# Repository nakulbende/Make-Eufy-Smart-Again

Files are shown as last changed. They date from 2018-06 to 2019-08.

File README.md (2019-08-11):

# Make Eufy smart again!

Make a internet enabled IR controller for EUFY vacuum cleaners. Recent models of EUFY and Roomba vacuum cleaners include smartphone control, and my robot was feeling left out. So - lets make EUFY smart again!

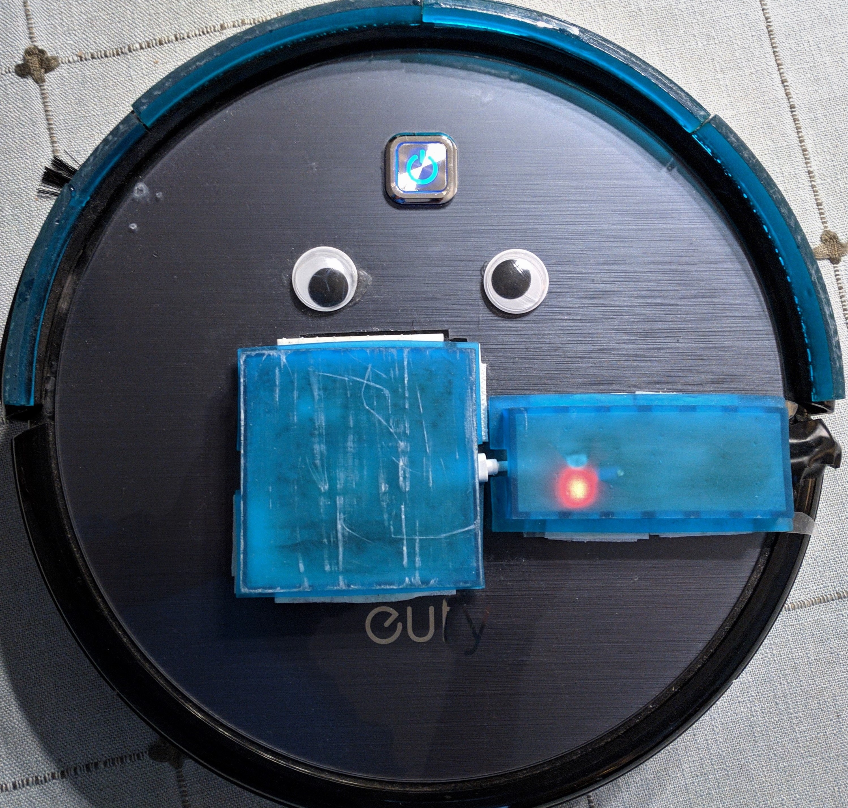
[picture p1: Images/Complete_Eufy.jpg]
Smart EUFY


## What you need: 

- EUFY vacuum cleaner: [non-internet enabled models v11, v11s and v11+](https://www.eufylife.com/collections/cleaning)
- ESP8266 based microcontroller: we use a [esp8266 12E mounted on a nodeMCU devboard v0.9](https://frightanic.com/iot/comparison-of-esp8266-nodemcu-development-boards/) used here, Adafruit Huzzah or any other internet enabled board can be used too
- ~~Battery pack: Slimmer and bigger mAh is better - current example uses a [12000 mAh battery charger](https://smile.amazon.com/gp/product/B077N9KYV8/ref=oh_aui_detailpage_o03_s00?ie=UTF8&psc=1)~~
- **Updated for driving power from Eufy's battery** High efficiency buck convertor for converting 12V from [LM2596S DC to DC Step-down voltage regulator](https://www.ebay.com/itm/1x-10x-LM2596S-DC-DC-3A-Buck-Adjustable-Step-down-Power-Supply-Converter-Module/332711109230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). Uses low energy, low heat output, and now Eufy can be connected all the time!
- IR reciever: [VS1838B](https://smile.amazon.com/Haobase-pairs-Infrared-Emission-Receiver/dp/B01EMXC5XA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) based. Wiring and further details [here](https://chioszrobots.com/2014/02/11/vs1838-tl1838-vs1838b-universal-infrared-receiving-head-remote-control/)
- IR LED: [950 nm](https://smile.amazon.com/Haobase-pairs-Infrared-Emission-Receiver/dp/B01EMXC5XA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) Used like a regular LED
- Misc. supplies: Soldering supplies, wires, proto board, command strip (to mount controller, battery pack)

## Working principle: 

1. This project relies on copying IR codes from the supplied remote, meant for programming EUFY. The idea is to mount a low profile, internet enabled remote on the robot to make it 'smart'. Decoded codes for [Eufy v11](Codes_eufy_v11.txt) are included here. PLEASE PAY ATTENTION TO THE MODEL/ VERSION BEFORE POSTING ISSUES. To avoid issues with revisions/ model differences, please copy the IR codes from supplied remote as discussed shortly. 

2. This project uses the fantastic Blynk project to control board using web requests, and package everything in a nice GUI. Using Blynk servers, we can also enable Google home/ Alexa support using IFTTT. Highly recommend reading through [Blynk docs](http://docs.blynk.cc/) for a basic overview of how it works. 

3. An IR blaster controlled by esp8266, will replay the codes as if they were coming from EUFY's original remote. 

Here is a step-by-step guide for reading IR codes > designing circuit > programming esp8266 > making Blynk GUI > integrating with IFTTT (and optionally with Google Home)

### Reading IR codes from EUFY's remote: (skip if using EUFY v11 - codes are already included in this project)

All the IR send/ recieve commands are interfaced using cyborg5's amazing [IRLib2](https://github.com/cyborg5/IRLib2). Install it from library manager, or follow instructions on repo's github page. Based on library's example [rawRecv](https://github.com/cyborg5/IRLib2/blob/master/IRLib2/examples/rawRecv/rawRecv.ino), we will be reading IR codes with any arduino based board programmed with ([IR_read_RAW_codes](IR_read_RAW_codes/IR_read_RAW_codes.ino). To equip the IR reciever, simply connect pins to 3.3V, GND and digital pin 2. Flash the board with [included code](IR_read_RAW_codes/IR_read_RAW_codes.ino), and open serial monitor with appropriat baud rate. Take your EUFY remote, point it at the reciever, and voila! The code will print the RAW IR code for that particular button. The EUFY's IR reciever is indeed following the exact same procedure to read IR signals from its remote!

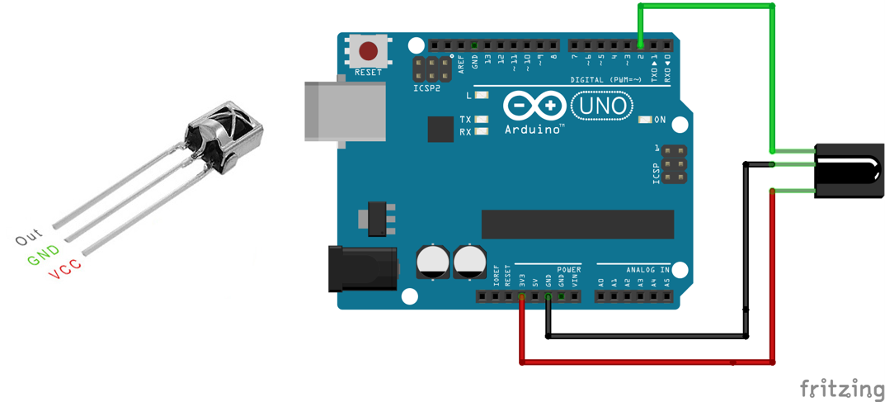
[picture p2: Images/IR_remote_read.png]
Circuit for copying IR codes


For the geeks and nerds out there, most consumer IR signals are carried on a 38kHz carrier frequency, which is also the case here. Some major brands like SONY, NEC and PANASONIC have HEX codes associated with this RAW data, and can be decoded using IRLib2. Since EUFY does not follow any of these standard codes - we will just read and send RAW IR codes - simply an array of numbers representing how long the LEd was ON, followed by how long it was OFF for.

For example, when HOME button is pressed, the raw IR code on serial port is: 

```
Encoding  : UNKNOWN
Code      : E8BEB62D (32 bits)
Timing[83]:
     +2900, -3000     + 500, - 500     + 550, -1400     + 550, -1450
     + 500, - 450     + 550, -1450     + 500, - 450     + 550, - 450
     + 550, - 400     + 550, - 450     + 450, - 550     + 450, - 550
     + 450, - 500     + 550, -1450     + 500, -1450     + 550, -1400
     + 600, -1400     + 550, - 450     + 500, - 450     + 600, - 400
     + 550, - 450     + 500, - 450     + 550, - 450     + 500, - 500
     + 500, - 450     + 450, - 550     + 550, - 450     + 500, - 450
     + 550, - 450     + 550, - 450     + 550, - 450     + 500, - 450
     + 550, - 450     + 550, - 450     + 550, -1400     + 550, -1450
     + 550, -1400     + 450, - 500     + 550, -1450     + 450, -1500
     + 550, -1450     + 550
unsigned int  rawData[83] = {2900,3000, 500,500, 550,1400, 550,1450, 500,450, 550,1450, 500,450, 550,450, 550,400, 550,450, 450,550, 450,550, 450,500, 550,1450, 500,1450, 550,1400, 600,1400, 550,450, 500,450, 600,400, 550,450, 500,450, 550,450, 500,500, 500,450, 450,550, 550,450, 500,450, 550,450, 550,450, 550,450, 500,450, 550,450, 550,450, 550,1400, 550,1450, 550,1400, 450,500, 550,1450, 450,1500, 550,1450, 550};  // UNKNOWN E8BEB62D
```
This denotes a box wave with the led ON for 2900ms, OFF for 3000ms, ON for 500ms, OFF for 450ms and so on. Pressing the same button a couple of times should be used to check consistency of these numbers. Finally, the raw code should be "cleaned" by rounding numbers to obvious extremes: 2900 goes to 3000, 450 and 550 to 500, 1400 to 1500 etc. This is to account for limited resolution. In essence, this same code should have been: 

```
Encoding  : UNKNOWN
Code      : E8BEB62D (32 bits)
Timing[83]:
     +3000, -3000     + 500, - 500     + 500, -1500     + 500, -1500
     + 500, - 500     + 500, -1500     + 500, - 500     + 500, - 500
     + 500, - 500     + 500, - 500     + 500, - 500     + 500, - 500
     + 500, - 500     + 500, -1500     + 500, -1500     + 500, -1500
     + 500, -1500     + 500, - 500     + 500, - 500     + 500, - 500
     + 500, - 500     + 500, - 500     + 500, - 500     + 500, - 500
     + 500, - 500     + 500, - 500     + 500, - 500     + 500, - 500
     + 500, - 500     + 500, - 500     + 500, - 500     + 500, - 500
     + 500, - 500     + 500, - 500     + 500, -1500     + 500, -1500
     + 500, -1500     + 500, - 500     + 500, -1500     + 500, -1500
     + 500, -1500     + 500
unsigned int  rawData[83] = {3000,3000, 500,500, 500,1500, 500,1500, 500,500, 500,1500, 500,500, 500,500, 500,500, 500,500, 500,500, 500,500, 500,500, 500,1500, 500,1500, 500,1500, 500,1500, 500,500, 500,500, 500,500, 500,500, 500,500, 500,500, 500,500, 500,500, 500,500, 500,500, 500,500, 500,500, 500,500, 500,500, 500,500, 500,500, 500,500, 500,1500, 500,1500, 500,1500, 500,500, 500,1500, 500,1500, 500,1500, 500};  // UNKNOWN E8BEB62D
```

[Included codes](Codes_eufy_v11.txt) for EUFY 11 are cleaned and ready to go!

### Circuit for transmitting IR codes using esp8266

The ESP is a wonderful device - packing wifi, digital/ analog IO in such a small footprint is no small feat of engineering. Chinese manufacturers do not get credit for their innovation - ESP is definately an hallmark from Espressif Systems! We will be using a nodeMCU developer board - you can certainly use a esp8266-12E directly if you do not have the board. This is how the circuit should be connected, and the final product: 

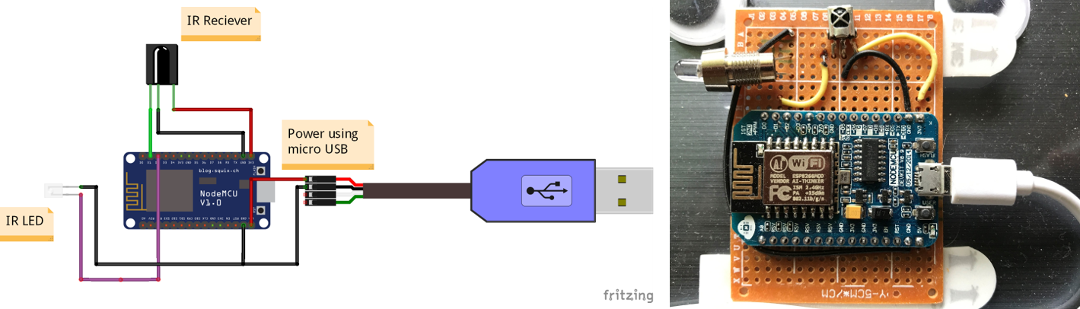
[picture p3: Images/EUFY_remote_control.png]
Circuit and actual product


Mounting options will be discussed later - but make sure you do not block the IR blaster with box/ mounts.  

### Programming esp8266

Flash esp8266 with the [supplied code](/IR_remote_control_EUFY_github/IR_remote_control_EUFY_github.ino) using following settings: 

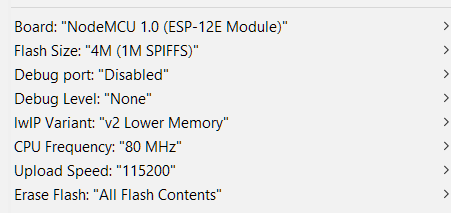
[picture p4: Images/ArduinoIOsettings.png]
Flash settings


The following snippets describe what this code does:

#### [Lines 10 - 15](https://github.com/nakulbende/Make-Eufy-Smart-Again/blob/master/IR_remote_control_EUFY_github/IR_remote_control_EUFY_github.ino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) define connection settings: change according to your Wifi settings and Blynk authentication code

10-12     Define `ssid` and `password` according to wifi settings. 

13        Add new device in Blynk mobile app, and define the authorization token as `auth` 

14-15     We will be pushing over the air updates to your esp8266 to make any changes after first time, so define the `OTAName` and `OTAPassword` to identify and secure it. 

#### [Lines 18 and 19](https://github.com/nakulbende/Make-Eufy-Smart-Again/blob/master/IR_remote_control_EUFY_github/IR_remote_control_EUFY_github.ino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) define the pins on which devices are connected to

Define the GPIO for IR blaster as `IR_LED` and IR reciever as `IR_RECV`. Be careful if nodeMCU dev board is used - enter the actual GPIO pins connected to devices, not the identifiers on board. 

#### [Lines 24-39](https://github.com/nakulbende/Make-Eufy-Smart-Again/blob/master/IR_remote_control_EUFY_github/IR_remote_control_EUFY_github.ino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) define virtual pins for controlling the esp8266 through Blynk

[Virtual pins used in Blynk](http://docs.blynk.cc/#blynk-main-operations-virtual-pins) are defined using `VPIN_*` for all the commands copied from remote. Custom pins such as `VPIN_Connected` and `VPIN_terminal` are used for monitoring connection status and terminal output using Blynk app.

#### [Lines 53-87](https://github.com/nakulbende/Make-Eufy-Smart-Again/blob/master/IR_remote_control_EUFY_github/IR_remote_control_EUFY_github.ino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) define previously copied IR codes 

Store the previously copied IR codes in structured arrays `ir_*`. Change the value of each variable with cleaned values if you are using a different version of EUFY vacuum cleaner. 

#### Rest of the code can be left as is. Upon booting, the device should connect to internet and Blynk servers

### Configuring Blynk GUI:

The virtual pins defined in code (and discussed in previous section) can be assigned to individual buttons in Blynk app. An example of such GUI in making can be seen in following screenshots - feel free to alter or use as is. Although the widgets and settings are self explanatory - [Blynk Widget guide](http://docs.blynk.cc/#widgets) is a great resource!

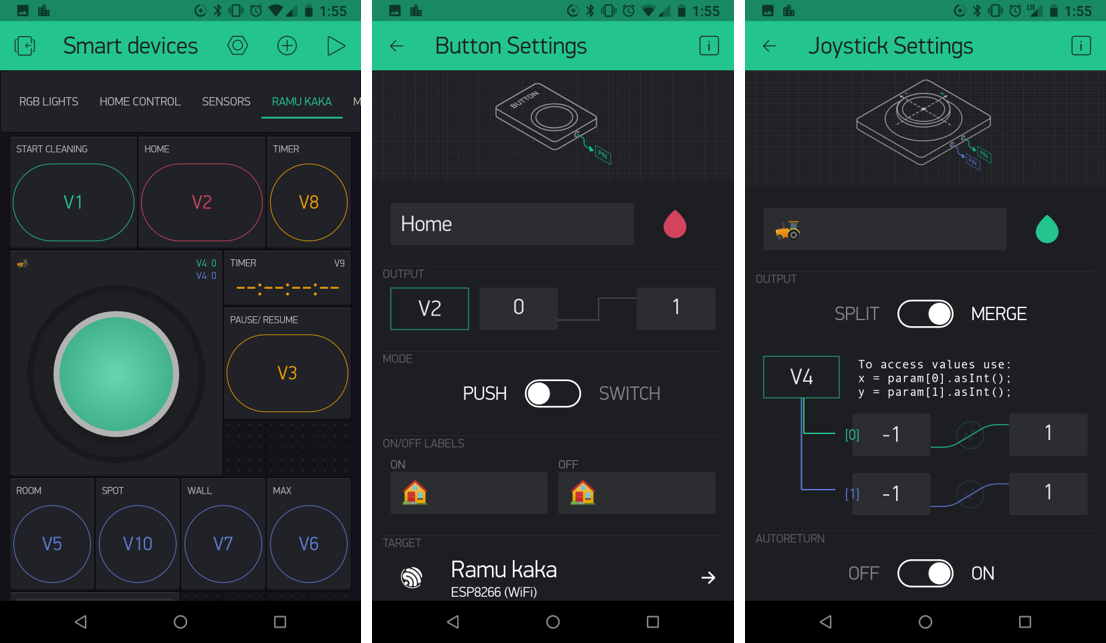
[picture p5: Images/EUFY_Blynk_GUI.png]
Blynk GUI configuration


Finally, the EUFY remote functionality can be replicated on a smartphone. We made EUFY smart again!

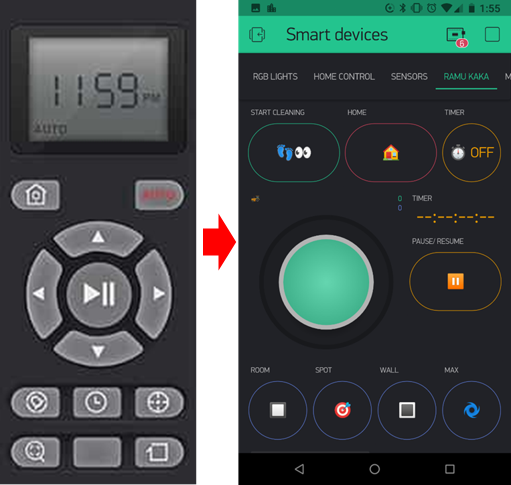
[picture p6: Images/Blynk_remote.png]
Blynk remote


### IFTTT/ Google Home/ Alexa integration

Read/ Write functions can be performed on Blynk virtual/ digital/ analog pins by putting data on the following URL: 

http://`IP: blynk server`/`device authorization code`/pin/`pin identifier`

`IP: blynk server` depends on your location. For US, it is 45.55.96.146. Open terminal and `ping blynk-cloud.com` to resolve the local IP address. Auth code helps in identifying the device, and pins can be defined as D1/ V1 etc. for digital or virtual pin. 

Once URL is ready - use any action to trigger a webhook with following settings. For example, configure gogle assistant trigger to post 1 on V1 for sending Auto clean command to EUFY, whenever it detects "clean the house"

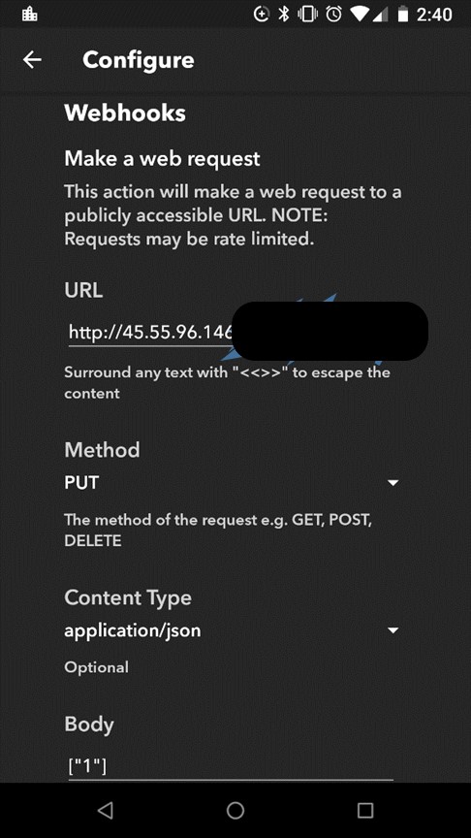
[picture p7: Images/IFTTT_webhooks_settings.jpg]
Webhooks setting


### Mounting options

~~The battery pack and circuit can be mounted on the EUFY using command strips. Due to this, a slim battery pack should be preffered. The product listed only raises the height of EUFY slighly. Getting power directly from the Eufy's battery is to be explored for future revisions. We have already tried getting power from the adapter jack besides the power button - which outputs a DC current, but also puts EUFY in charging mode if it detects a closed circuit.~~  

**Updated 8/11/2019**

Finally got around to posting this. I have converted this setup to be in an always ON state - powered directly by the Eufy's 12V battery. The setup now looks as follows: 

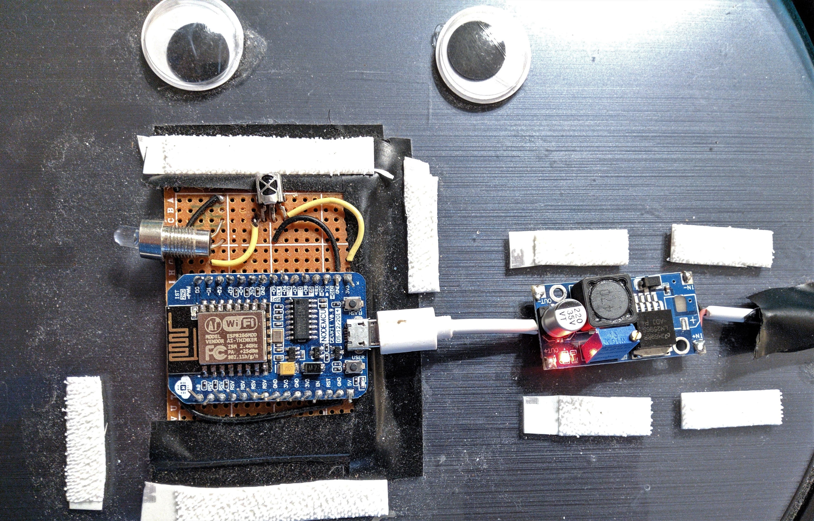
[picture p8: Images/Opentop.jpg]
Circuit, voltage regulator


I used a high efficiency voltage regulator (LM2596S) for converting 12V to 3V which esp8266 needs, and mounted everything using command strips. You do have to work on roputing the wire - I found that using a thin wire, routing it through the sides of bumper like follows works pretty well: 

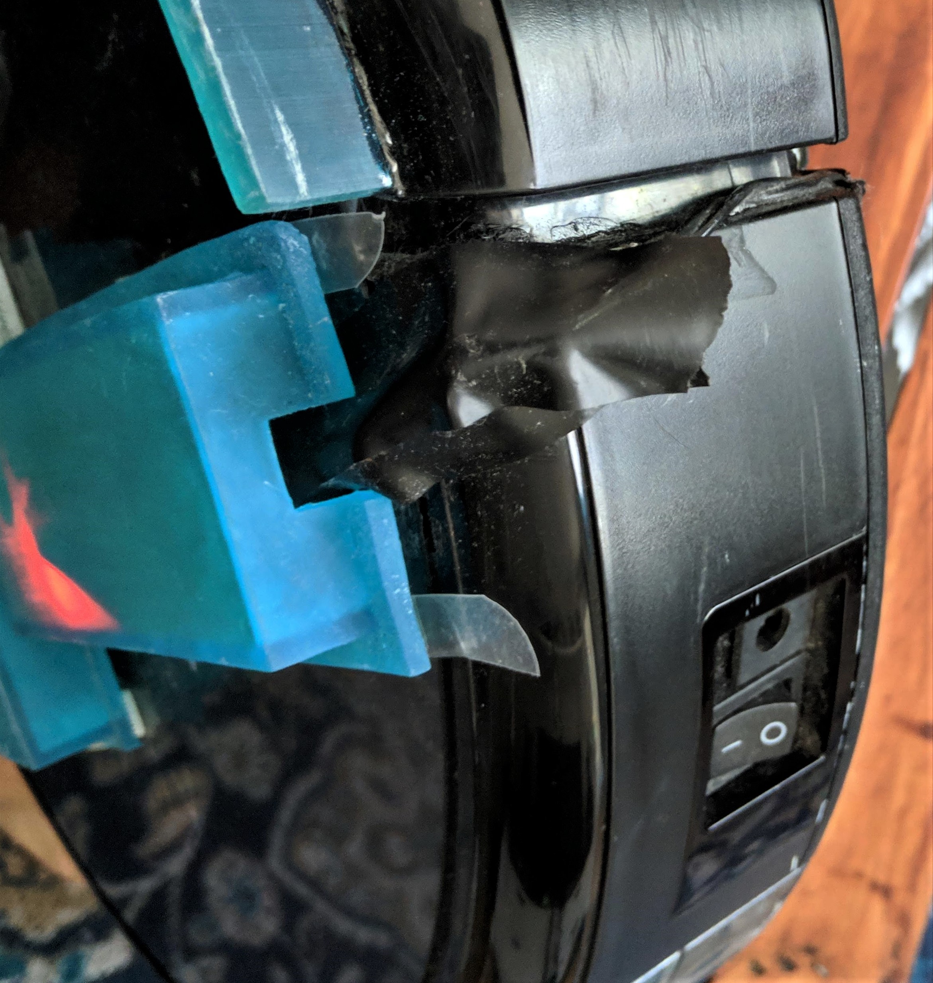
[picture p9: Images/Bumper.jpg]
Routing wire from side, to the belly


Once you have access to Eufy's belly, you can just route the wire to battery compartment. I made a little hole on cover using my soldering iron. There, just slice wires, and take power directly from the battery. 

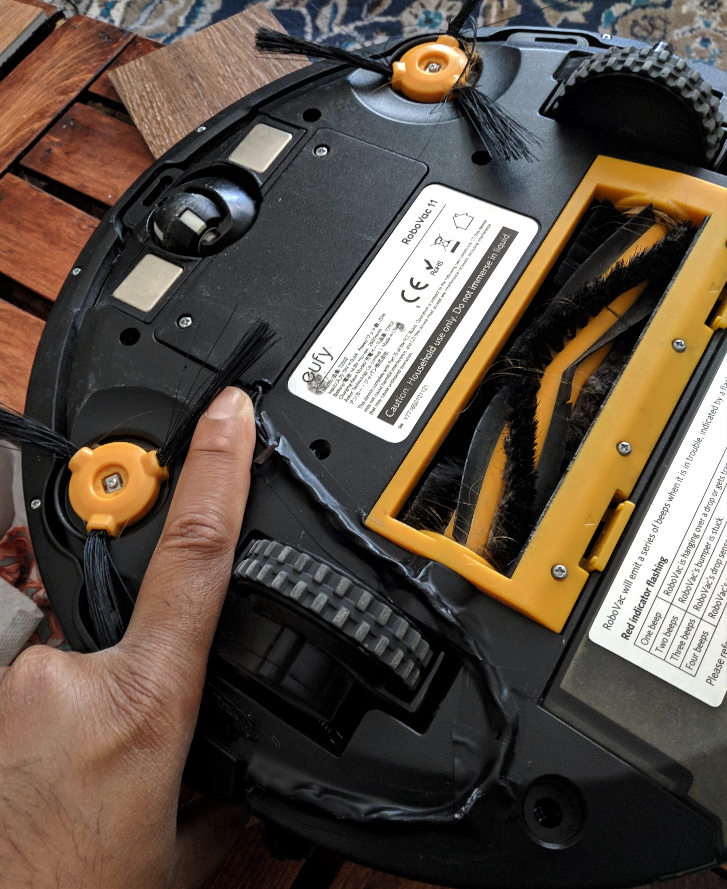
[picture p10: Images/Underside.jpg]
Underside


I then secured all the wires using electrical tape, laden with superglue. It makes a nice sealed conduit for your wires. 

### Enclosures, and bumper modification

One might notice all the 3d printed parts on cleaner. These not only protect the parasitic electronics that are taking a ride with our Eufy, but also increase the height of bumper to make sure the cleaner does not go under something and rip off the electroinics. All 3d printed files are in Images folder. 

### Previous revisions:

- ~~With a 12000 mAh battery, the eps8266 in this circuit runs for a week. Future versions will explore putting ESP in sleep/ switch off telemetry at night~~ **Dropped due to unreliable wakeup on esp's side**
- Powering with Eufy's very capable battery - get rid of the battery pack altogather. **Update - successful**

- This is how it looked before, when I used a battery pack: 

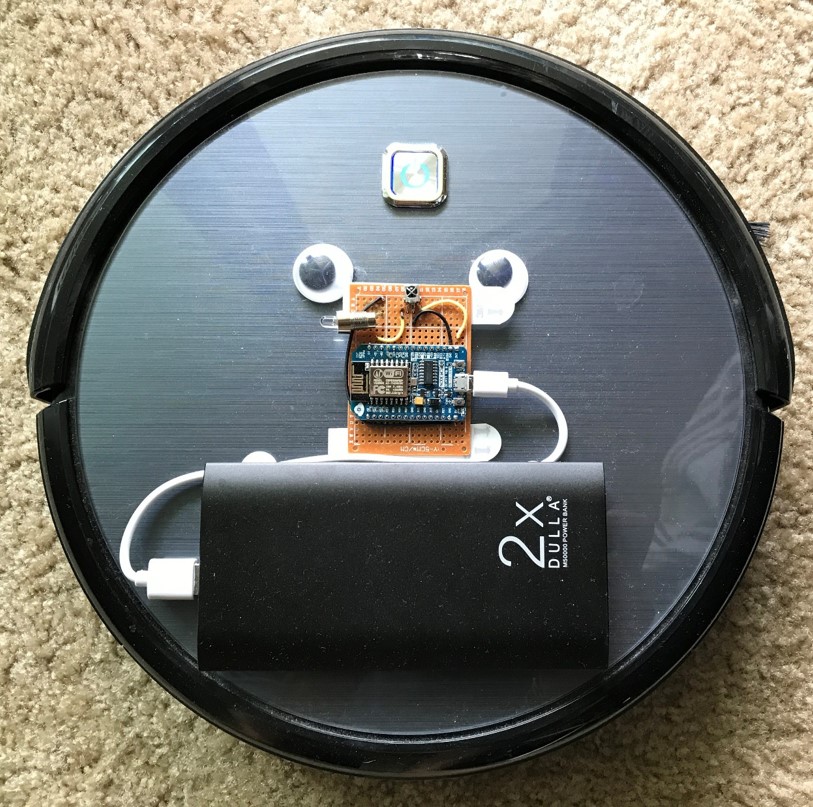
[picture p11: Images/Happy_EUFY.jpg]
Happy EUFY


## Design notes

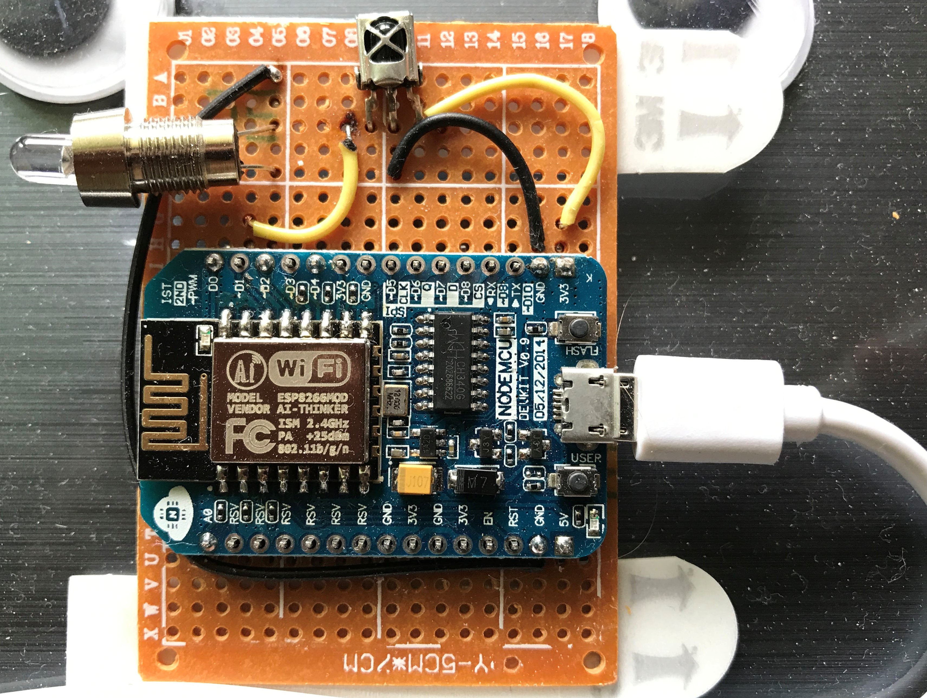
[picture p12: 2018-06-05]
Circuit.JPG

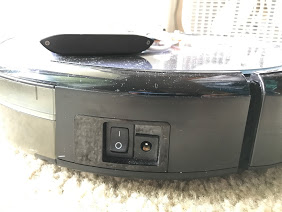
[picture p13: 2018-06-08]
Images/EUFY_side_port.JPG

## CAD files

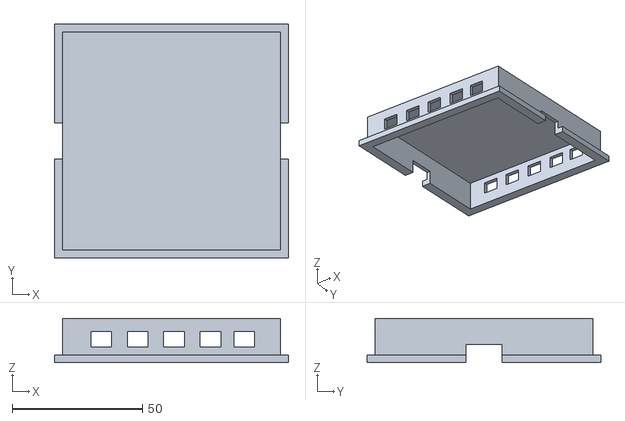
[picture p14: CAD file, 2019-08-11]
Images/esp8266 cover.stl
90.0 x 90.0 x 17.0

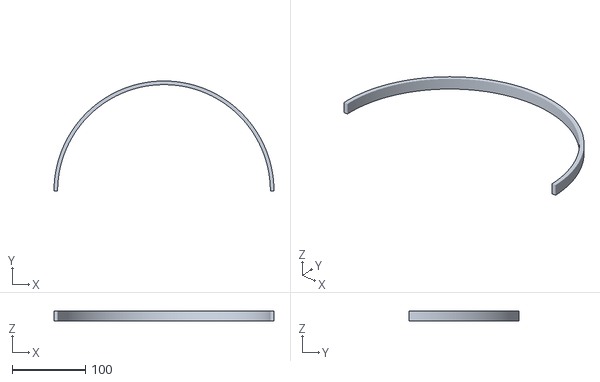
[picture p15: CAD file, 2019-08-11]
Images/bumper.stl
300.0 x 150.0 x 13.0

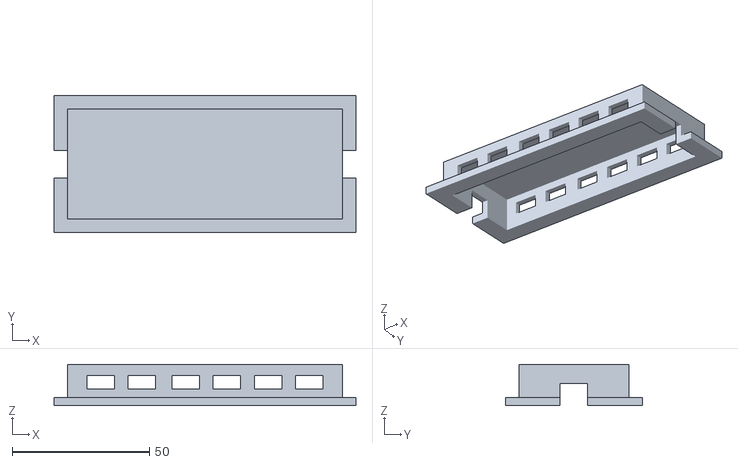
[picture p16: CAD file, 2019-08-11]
Images/wire and power supply.stl
110.0 x 50.0 x 15.0

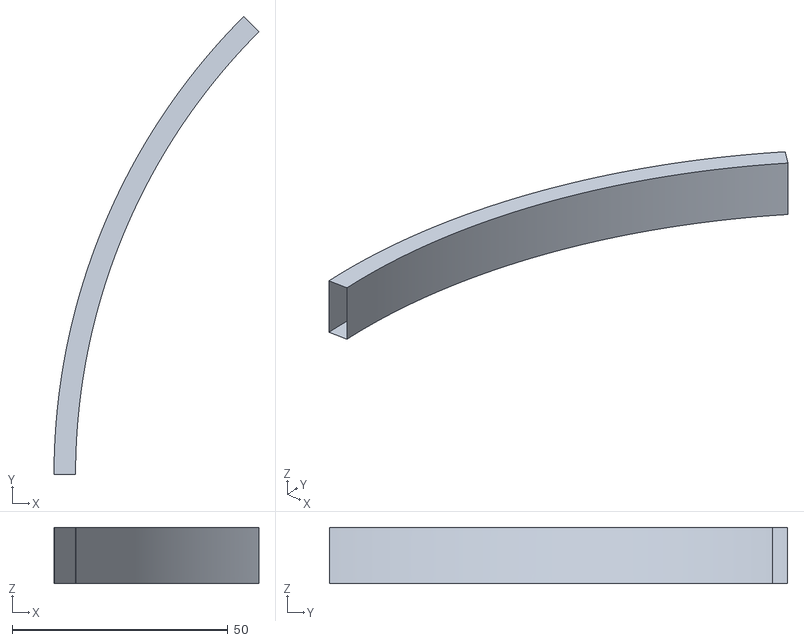
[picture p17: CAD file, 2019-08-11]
Images/bumper_arc.stl
47.5 x 106.1 x 13.0

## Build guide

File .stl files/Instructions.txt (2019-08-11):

Use these to print enclosures and bumper

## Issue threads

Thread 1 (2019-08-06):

energy savings

jellevervloessem, 2019-08-06:
Hi @nakulbende,

Do you have any update on exploring to putting ESP in sleep/ switch off telemetry at night?

nakulbende, 2019-08-06:
I do, lemme write this up.

------------Sent from phone----------

Nakul Bende,

Materials Scientist, Formlabs Inc.

http://nakulbende.com

On Tue, Aug 6, 2019, 7:52 AM Jelle Vervloessem <notifications@github.com>
wrote:

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

nakulbende, 2019-08-11:
Heyo, I updated my github repo
https://github.com/nakulbende/Make-Eufy-Smart-Again

I dropped wake/ skeep plan as it is quite unreliable. Alternatively, I just
powered it directly from Eufy's battery, which works like a charm. > 6
months without an issue.

Nakul Bende,

Materials Scientist, Formlabs Inc.

http://nakulbende.com

- Ever tried. Ever failed. Try Again. Fail again. Fail better.

--Samuel Beckett

On Tue, Aug 6, 2019 at 7:52 AM Jelle Vervloessem <notifications@github.com>
wrote:

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

Closed 2020-06-16.

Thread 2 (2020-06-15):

Question...unmounted?

vulcanjedi, 2020-06-15:
But curious why this has to be mounted at all?
is it because the IR signal not strong enough?
I was hoping to find a project such as this where small esp8266 close enough to the base to just start adhoc cleaning when I wanted?
Currently we have the robovac in the basement and we have a ledge across the room I was hoping to just aim the esp from?
Would this use case work?
Sorry this would be my first esp8266 project

nakulbende, 2020-06-16:
Hey,

Thanks for searchng through my repo - yes youc an have the esp8266
anywhere. Honestly, if you Eufy/ cleaner is constrained to one room, it
might be a lot easier to do that, and just power through a USB outlet. I
mounted it for having all-time control even when it is going to other rooms
that the one my base is in.

I think IR signals are pretty good, not omnipresent, but good enough for a
single room. Good idea!

Nakul Bende,

Materials Scientist, Formlabs Inc.

http://nakulbende.com

- Ever tried. Ever failed. Try Again. Fail again. Fail better.

--Samuel Beckett

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

vulcanjedi, 2020-06-16:
Thanks for reply, super excited to try to take this on.  Maybe relcoate the base to be more centrally located so it can return to the base. Currently shutting the doors to other rooms since we dont frquent the basement all that much yet. But yeah I think the mount is too much for me, but was still hoping to try the project as  good learning opportunity. Thanks for sharing.

nakulbende, 2020-06-16:
ESp8266 is awesome - choose your module well if you havent bought. I would
go for one of the nodemcu dev board - no need to make a flashing circuits
and all - and it already has a usb port which you can use to charge. Good
luck! Happy to help, and do share photos!

Nakul Bende,

Materials Scientist, Formlabs Inc.

http://nakulbende.com

- Ever tried. Ever failed. Try Again. Fail again. Fail better.

--Samuel Beckett

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

Closed 2020-06-16.

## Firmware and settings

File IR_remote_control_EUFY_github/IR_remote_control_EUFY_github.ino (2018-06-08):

#include <ESP8266WiFi.h>        // Wifi library for ESP
#include <BlynkSimpleEsp8266.h> // Blynk library
#include <ArduinoOTA.h>         // Library for over the air updates
//#include <IRremote.h>         // IR remote
#include <IRremoteESP8266.h>    // IR remote lib for esp8266
#include <IRsend.h>             // IR sending
#include <IRrecv.h>
#include <math.h>

// Wifi, OTA, blynk credentials
const char* ssid = "XXXXXXXX";                              // SSID
const char* password = "XXXXXXXXXXXXXXX";                   // Password
char auth[] = "XXXXXXXXXXXX";                               // Token for Esp8266
const char* OTAName = "XXXXXXXXXXXX";                       // OTA name
const char* OTAPassword = "XXXXXXXXXXX";                    // OTA Password

// Prepare IR LED to be used
#define IR_LED 4                // ESP8266 GPIO pin to use for blaster (4 is D2 on nodeMCU devBoard)
#define IR_RECV 5               // ESP8266 GPIO pin to use for reciever (5 is D1 on nodeMCU devBoard)
IRrecv irrecv(IR_RECV);
IRsend irsend(IR_LED);          // Set the GPIO to send IR signals


// Pins for blynk
#define VPIN_clean V1           // Switch AUTO clean ON or OFF
#define VPIN_home V2            // Homing signal
#define VPIN_play V3            // Play/ pause
#define VPIN_dpad V4            // D-pad
#define VPIN_room V5            // Room
#define VPIN_max V6             // Max
#define VPIN_wall V7            // Wall
#define VPIN_timerONOFF V8      // Timer ON/ OFF
#define VPIN_timer V9           // Timer handle
#define VPIN_spot V10           // Spot

#define VPIN_everything V21     // Tag: everything can be used to group devices and give one command to switch off/ on everything connected to blynk app
#define VPIN_terminal V25       // Terminal monitoring through Blynk app

#define VPIN_connected V30      // Connection

// Define variables
boolean LampState = 0;
boolean SwitchReset = true;     // Flag indicating that the hardware button has been released
int khz = 38;                   // 38kHz carrier frequency
int Timer_status = 0;

// Start timer
BlynkTimer timer;

// Terminal for Blynk
WidgetTerminal terminal(VPIN_terminal);

// Define all the IR codes:

// Auto cleaning
uint16_t ir_auto[83] = {3000,3000, 500,500, 500,1500, 500,1500, 500,500, 500,1500, 500,500, 500,500, 500,500, 500,1500, 500,500, 500,1500, 500,500, 500,500, 500,500, 500,500, 500,500, 500,500, 500,500, 500,500, 500,500, 500,500, 500,500, 500,500, 500,500, 500,500, 500,500, 500,500, 500,500, 500,500, 500,500, 500,500, 500,500, 500,500, 500,500, 500,500, 500,500, 500,1500, 500,500, 500,500, 500,500, 500};  // UNKNOWN E474C5C6

// Home
uint16_t ir_home[83] = {3000,3000, 500,500, 500,1500, 500,1500, 500,500, 500,1500, 500,500, 500,500, 500,500, 500,500, 500,500, 500,500, 500,500, 500,1500, 500,1500, 500,1500, 500,1500, 500,500, 500,500, 500,500, 500,500, 500,500, 500,500, 500,500, 500,500, 500,500, 500,500, 500,500, 500,500, 500,500, 500,500, 500,500, 500,500, 500,500, 500,1500, 500,1500, 500,1500, 500,500, 500,1500, 500,1500, 500,1500, 500};  // UNKNOWN E8BEB62D

// Play
uint16_t ir_play[83] = {3000,3000, 500,500, 500,1500, 500,1500, 500,500, 500,1500, 500,500, 500,500, 500,500, 500,1500, 500,1500, 500,1500, 500,1500, 500,500, 500,1500, 500,500, 500,1500, 500,500, 500,500, 500,500, 500,500, 500,500, 500,500, 500,500, 500,500, 500,500, 500,500, 500,500, 500,500, 500,500, 500,500, 500,500, 500,500, 500,500, 500,1500, 500,500, 500,1500, 500,1500, 500,1500, 500,500, 500,1500, 500};  // UNKNOWN C1C301C7

// Pause
uint16_t ir_pause[83] = {3000,3000, 500,500, 500,1500, 500,1500, 500,500, 500,1500, 500,500, 500,500, 500,500, 500,1500, 500,1500, 500,1500, 500,1500, 500,500, 500,500, 500,500, 500,500, 500,500, 500,500, 500,500, 500,500, 500,500, 500,500, 500,500, 500,500, 500,500, 500,500, 500,500, 500,500, 500,500, 500,500, 500,500, 500,500, 500,500, 500,1500, 500,500, 500,1500, 500,1500, 500,500, 500,500, 500,500, 500};  // UNKNOWN 25638DD6

// D-pad directionality
//UP
uint16_t ir_up[83] = {3000,3000, 500,500, 500,1500, 500,1500, 500,500, 500,1500, 500,500, 500,500, 500,500, 500,1500, 500,500, 500,1500, 500,500, 500,500, 500,500, 500,1500, 500,500, 500,500, 500,500, 500,500, 500,500, 500,500, 500,500, 500,500, 500,500, 500,500, 500,500, 500,500, 500,500, 500,500, 500,500, 500,500, 500,500, 500,500, 500,500, 500,500, 500,500, 500,1500, 500,500, 500,1500, 500,500, 500};  // UNKNOWN A64BA26E
//Down
uint16_t ir_down[83] = {3000,3000, 500,500, 500,1500, 500,1500, 500,500, 500,1500, 500,500, 500,500, 500,500, 500,1500, 500,500, 500,1500, 500,1500, 500,500, 500,500, 500,1500, 500,1500, 500,500, 500,500, 500,500, 500,500, 500,500, 500,500, 500,500, 500,500, 500,500, 500,500, 500,500, 500,500, 500,500, 500,500, 500,500, 500,500, 500,500, 500,500, 500,500, 500,1500, 500,1500, 500,500, 500,1500, 500,1500, 500};  // UNKNOWN 9358E535
//Right
uint16_t ir_right[83] = {3000,3000, 500,500, 500,1500, 500,1500, 500,500, 500,1500, 500,500, 500,500, 500,500, 500,1500, 500,1500, 500,500, 500,1500, 500,500, 500,1500, 500,500, 500,1500, 500,500, 500,500, 500,500, 500,500, 500,500, 500,500, 500,500, 500,500, 500,500, 500,500, 500,500, 500,500, 500,500, 500,500, 500,500, 500,500, 500,500, 500,500, 500,1500, 500,1500, 500,1500, 500,1500, 500,500, 500,1500, 500};  // UNKNOWN 66F1D5CF
//Left
uint16_t ir_left[83] = {3000,3000, 500,500, 500,1500, 500,1500, 500,500, 500,1500, 500,500, 500,500, 500,500, 500,1500, 500,1500, 500,500, 500,500, 500,500, 500,1500, 500,1500, 500,500, 500,500, 500,500, 500,500, 500,500, 500,500, 500,500, 500,500, 500,500, 500,500, 500,500, 500,500, 500,500, 500,500, 500,500, 500,500, 500,500, 500,500, 500,500, 500,1500, 500,500, 500,1500, 500,1500, 500,1500, 500,500, 500};  // UNKNOWN 1DD91AB0

// Single room
uint16_t ir_room[83] = {3000,3000, 500,500, 500,1500, 500,1500, 500,500, 500,1500, 500,500, 500,500, 500,500, 500,500, 500,500, 500,1500, 500,1500, 500,500, 500,1500, 500,500, 500,500, 500,500, 500,500, 500,500, 500,500, 500,500, 500,500, 500,500, 500,500, 500,500, 500,500, 500,500, 500,500, 500,500, 500,500, 500,500, 500,500, 500,1500, 500,500, 500,500, 500,1500, 500,1500, 500,1500, 500,500, 500,500, 500};  // UNKNOWN 1A8F2EB8

// Max cleaning
uint16_t ir_max[83] = {3000,3000, 500,500, 500,1500, 500,1500, 500,500, 500,1500, 500,500, 500,500, 500,500, 500,500, 500,500, 500,500, 500,1500, 500,500, 500,500, 500,1500, 500,1500, 500,500, 500,500, 500,500, 500,500, 500,500, 500,500, 500,500, 500,500, 500,500, 500,500, 500,500, 500,500, 500,500, 500,500, 500,500, 500,500, 500,500, 500,1500, 500,1500, 500,1500, 500,1500, 500,500, 500,1500, 500,1500, 500};  // UNKNOWN A2B091CB

// Wall cleaning
uint16_t ir_wall[83] = {3000,3000, 500,500, 500,1500, 500,1500, 500,500, 500,1500, 500,500, 500,500, 500,500, 500,500, 500,500, 500,1500, 500,500, 500,500, 500,500, 500,1500, 500,1500, 500,500, 500,500, 500,500, 500,500, 500,500, 500,500, 500,500, 500,500, 500,500, 500,500, 500,500, 500,500, 500,500, 500,500, 500,500, 500,500, 500,1500, 500,500, 500,500, 500,500, 500,1500, 500,500, 500,1500, 500,1500, 500};  // UNKNOWN FFB2DFB1

// Spot cleaning
uint16_t ir_spot[83] = {3000,3000, 500,500, 500,1500, 500,1500, 500,500, 500,1500, 500,500, 500,500, 500,500, 500,500, 500,500, 500,1500, 500,500, 500,500, 500,500, 500,1500, 500,1500, 500,500, 500,500, 500,500, 500,500, 500,500, 500,500, 500,500, 500,500, 500,500, 500,500, 500,500, 500,500, 500,500, 500,500, 500,500, 500,500, 500,1500, 500,500, 500,500, 500,500, 500,1500, 500,500, 500,1500, 500,1500, 500};  // UNKNOWN FFB2DFB1

void setup()
{
  // Serial port
  //Serial.begin(74880, SERIAL_8N1, SERIAL_TX_ONLY);
  Serial.begin(74880);
  Serial.println("Starting vacuum cleaner controller");

  // Wifi connection and services
  startWiFi();                      // Connect to WIFI
  startOTA();                       // Start OTA servers

  // Check internet connection every 5 minutes
  timer.setInterval(300000L, CheckConnection); // check if still connected every 5 minutes  

  // Start configuration
  Blynk.config(auth);               // Connect to Blynk
  Blynk.connect();

  // WDT handling
  ESP.wdtDisable();
  ESP.wdtEnable(WDTO_8S);
  timer.setInterval(100000, WDT);

  irsend.begin();
  irrecv.enableIRIn(); // Start the receiver
}

void CheckConnection(){    // check every 5 minutes if connected to Blynk server
  if(!Blynk.connected()){
    Serial.println("Not connected to Blynk server"); 
    Blynk.connect();  // try to connect to server with default timeout
  }
  else{
    Serial.println("Connected to Blynk server");  
    terminal.println("Connected to Blynk server");  
    Blynk.virtualWrite(VPIN_connected, 1);   // Denote that ESP is connected to Blynk server
  }
}

void loop() {
  if(Blynk.connected()){
    Blynk.run();
  }
  ArduinoOTA.handle();
  timer.run();
}

BLYNK_CONNECTED() {
    Blynk.syncAll();
}

// Start cleaning in auto mode
BLYNK_WRITE(VPIN_clean){
  int Clean_button = param.asInt();
  if (Clean_button == 1){
    irsend.sendRaw(ir_auto, 83, khz);   // Send Auto Clean signal on press
    Blynk.virtualWrite(VPIN_play, 1);   // Denote that vacuum cleaner is in a cleaning mode
    delay(300);
    terminal.println("Eufy will clean the rooms");
  }
}

// Send Vacuum cleaner home
BLYNK_WRITE(VPIN_home){
  int Clean_button = param.asInt();
  if (Clean_button == 1){
    irsend.sendRaw(ir_home, 83, khz);   // Send Home signal on press
    Blynk.virtualWrite(VPIN_play, 0);   // Denote that vacuum cleaner is not in a cleaning mode
    delay(300);
    terminal.println("Bedeep boop beep, going home");
  }
}

//
BLYNK_WRITE(VPIN_play){
  int Clean_button = param.asInt();
  if (Clean_button == 1){
    irsend.sendRaw(ir_play, 83, khz);   // Send Play signal on press
    Blynk.virtualWrite(VPIN_play, 1);   // Denote that vacuum cleaner is in a cleaning mode
    delay(300);
    terminal.println("Resuming the robot");
    }
    else if (Clean_button == 0) {
    irsend.sendRaw(ir_pause, 83, khz);   // Send Pause signal on press
    Blynk.virtualWrite(VPIN_play, 0);   // Denote that vacuum cleaner is not in a cleaning mode
    delay(300);
    terminal.println("Pausing the robot");
    }
}

// Navigate using the D-PAD
BLYNK_WRITE(VPIN_dpad){
  float x_pos = param[0].asFloat();
  float y_pos = param[1].asFloat();
  int x = round(x_pos); //Rounding to get only directional answers
  int y = round(y_pos);

  if (x == 1 && y == 0){ // right
    irsend.sendRaw(ir_right, 83, khz);   // Send Right signal on press
    Blynk.virtualWrite(VPIN_play, 1);   // Denote that vacuum cleaner is in a cleaning mode
    terminal.println("Wooo...going right");
  }
  else if (x == -1 && y == 0){ //left
    irsend.sendRaw(ir_left, 83, khz);   // Send Left signal on press
    Blynk.virtualWrite(VPIN_play, 1);   // Denote that vacuum cleaner is in a cleaning mode
    terminal.println("Wooo...going left");
  }
  else if (x == 0 && y == 1){ //up
    irsend.sendRaw(ir_up, 83, khz);   // Send Up signal on press
    Blynk.virtualWrite(VPIN_play, 1);   // Denote that vacuum cleaner is in a cleaning mode
    terminal.println("Wooo...going up");
  }
  else if (x == 0 && y == -1){ //down
    irsend.sendRaw(ir_down, 83, khz);   // Send Down signal on press
    Blynk.virtualWrite(VPIN_play, 1);   // Denote that vacuum cleaner is in a cleaning mode
    terminal.println("Wooo...going down");
  }
  else if (x == -1 && y == -1){ //left, down
    irsend.sendRaw(ir_down, 83, khz);   // Send Down signal on press
    irsend.sendRaw(ir_left, 83, khz);   // Send Left signal on press
    Blynk.virtualWrite(VPIN_play, 1);   // Denote that vacuum cleaner is in a cleaning mode
    terminal.println("Wooo...going left-down");
  }
}

// Start cleaning in room mode
BLYNK_WRITE(VPIN_room){
  int Clean_button = param.asInt();
  if (Clean_button == 1){
    irsend.sendRaw(ir_room, 83, khz);   // Send Room Cleaning signal on press
    Blynk.virtualWrite(VPIN_play, 1);   // Denote that vacuum cleaner is in a cleaning mode
    terminal.println("Clean you room!");
  }
}

// Start cleaning in max mode
BLYNK_WRITE(VPIN_max){
  int Clean_button = param.asInt();
  if (Clean_button == 1){
    irsend.sendRaw(ir_max, 83, khz);   // Send Max Cleaning signal on press
    Blynk.virtualWrite(VPIN_play, 1);   // Denote that vacuum cleaner is in a cleaning mode
    terminal.println("Cleaning for the queen!");
  }
}

// Start cleaning in wall mode
BLYNK_WRITE(VPIN_wall){
  int Clean_button = param.asInt();
  if (Clean_button == 1){
    irsend.sendRaw(ir_wall, 83, khz);   // Send Wall Cleaning signal on press
    Blynk.virtualWrite(VPIN_play, 1);   // Denote that vacuum cleaner is in a cleaning mode
    terminal.println("Wall clean!");
  }
}

// Start cleaning in spot mode
BLYNK_WRITE(VPIN_spot){
  int Clean_button = param.asInt();
  if (Clean_button == 1){
    irsend.sendRaw(ir_spot, 83, khz);   // Send Spot Cleaning signal on press
    Blynk.virtualWrite(VPIN_spot, 1);   // Denote that vacuum cleaner is in a cleaning mode
    terminal.println("Spot clean!");
  }
}

// Start cleaning according to a timer
BLYNK_WRITE(VPIN_timerONOFF){
  int Timer_status = param.asInt();
}

// Start cleaning according to a timer, only if the timer status is set to be used
BLYNK_WRITE(VPIN_timer){
  int Clean_button = param.asInt();
  if (Timer_status == 1 && Clean_button == 1){
    irsend.sendRaw(ir_auto, 83, khz);   // Send Auto Clean signal on press
    Blynk.virtualWrite(VPIN_play, 1);   // Denote that vacuum cleaner is in a cleaning mode
    terminal.println("I will clean it later!");
  }
}

// Feed the watchdog!
void WDT(){
  ESP.wdtFeed();
}

// Connect wifi
void startWiFi() { // Start a Wi-Fi access point, and try to connect to some given access points. Then wait for either an AP or STA connection
  WiFi.begin(ssid, password);                 // Connect to the network
  Serial.print("Connecting to ");
  Serial.print(ssid); Serial.println(" ...");
  int i = 0;
  while (WiFi.status() != WL_CONNECTED) {     // Wait for the Wi-Fi to connect
    delay(1000);
    Serial.print(++i); Serial.print(' ');
    i = i++;
    if (i > 300){
      break; // Exit after 5 minutes
    }
  }
  Serial.println('\n');
  Serial.println("Connection established!");
  Serial.print("IP address:\t");
  terminal.println("Connection established, IP address:\t");
  terminal.print(WiFi.localIP());
  Serial.println(WiFi.localIP());             // Print IP address
}

// Start to OTA server
void startOTA() {                             // Start the OTA service
  ArduinoOTA.setHostname(OTAName);            // Hostname for OTA
  ArduinoOTA.setPassword(OTAPassword);        // Password for OTA

  ArduinoOTA.onStart([]() {
    Serial.println("Start");
    terminal.println("Starting firmware flash");
  });
  ArduinoOTA.onEnd([]() {
    Serial.println("\r\nOTA Flash complete");
    terminal.println("\r\nOTA Flash is complete");
  });
  ArduinoOTA.onProgress([](unsigned int progress, unsigned int total) {
    Serial.printf("Progress: %u%%\r", (progress / (total / 100)));
    terminal.printf("Progress: %u%%\r", (progress / (total / 100)));
  });
  ArduinoOTA.onError([](ota_error_t error) {
    Serial.printf("Error[%u]: ", error);
    if (error == OTA_AUTH_ERROR) Serial.println("Auth Failed");
    else if (error == OTA_BEGIN_ERROR) Serial.println("Begin Failed");
    else if (error == OTA_CONNECT_ERROR) Serial.println("Connect Failed");
    else if (error == OTA_RECEIVE_ERROR) Serial.println("Receive Failed");
    else if (error == OTA_END_ERROR) Serial.println("End Failed");
  });
  ArduinoOTA.begin();
  Serial.println("OTA server ready\r\n");
}

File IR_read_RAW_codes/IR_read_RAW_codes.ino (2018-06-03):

#include "IRLibAll.h"
 
//Create a receiver object to listen on pin 2
IRrecvPCI myReceiver(2);
 
//Create a decoder object 
IRdecode myDecoder;   
 
void setup() {
  Serial.begin(9600);
  delay(2000); while (!Serial); //delay for Leonardo
  myReceiver.enableIRIn(); // Start the receiver
  Serial.println(F("Ready to receive IR signals"));
}
 
void loop() {
  //Continue looping until you get a complete signal received
  if (myReceiver.getResults()) {
    myDecoder.decode();           //Decode it
    myDecoder.dumpResults(true);  //Now print results. Use false for less detail
    myReceiver.enableIRIn();      //Restart receiver
  }
}
